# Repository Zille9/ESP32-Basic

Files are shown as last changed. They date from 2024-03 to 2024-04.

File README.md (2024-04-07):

# ESP32-Basic with FabGL VGA library + PS2-Keyboard
### Basic32+ with FabGL VGA library + PS2 PS2Controller for VGA monitor output - 2019 - 2023       
#### Ursprungsversion von: Rob Cai <rocaj74@gmail.com>
#### erweitert/modifiziert von:Reinhard Zielinski <zille09@gmail.com>                                                                   
#### Das Ergebnis ist ein kleiner Retro-Computer mit folgender Ausstattung:
- (Schaltplan siehe Ordner Schematic) 

## Hardware:
```
-ESP32 / 240MHz
-56472 Basic Bytes free
-VGA-Display 320x240 Pixel 64 Farben , AV (IO26) oder TFT-Screen 320x240 Pixel
-IO-Erweiterung mit MCP23017 (2x8 IO-Ports) + EEPROM 512kB 
-CardKb als PS2-Tastatur nutzbar (siehe Ordner <src/CardKeyBoard_neu>)
-Unterstützung von externem SPI-RAM 128kB, 512kB (Adafruit SPI-Fram) oder 2, 4 oder 8 MB PSRAM im SPI-Mode
-PS2-Keyboard 
-RTC DS3231 
-SD-Card
```

## Software:
```
Die Ursprungsversion wurde durch folgende Funktionen erweitert  

-fliesskomma Arithmetik
-Grafikfunktionen 	
-mathematische Funktionen 	
-Stringfunktionen 	
-lange Variablennamen  	
-viele zusätzliche Befehle (DATA,READ,STRG$,LEFT$,RIGHT$,MID$,POS,TAB,SPC,SIN,COS,TAN,ATN,LOG,SQR,PI usw.) 	
-erweiterte logische Operatoren (AND, OR) 	
-BIT-Manipulation &,|,%,<<,>> usw. 	
-Klammerrechnung 	
-IF THEN ELSE Abfragen 	
-Speichermonitor 	
-Exponential-Ein/Ausgabe 	
-Verschiedene Sensoren und Komponenten HC-S04, Dallas DS18S20, DHT, LCD, Neopixel-LED, BMP180 	
-Zeileneditor 
-BMP-Bilddatei-Import / Export
-Spritefunktionen (noch in der Entwicklung)
-Soundfunktionen (noch in der Entwicklung)
-integrierte Kurzhilfe
-Binärprogramme können mit RUN"/xxx.bin" gestartet werden - siehe Ordner <Software>

```

***Special Thanks on Guido Lehwalder and Marcelo Dantas ->RUN-CPM is a great Work!***

***Also thanks on Fabrizio Di Vittorio for the excellent FabGl-Library***



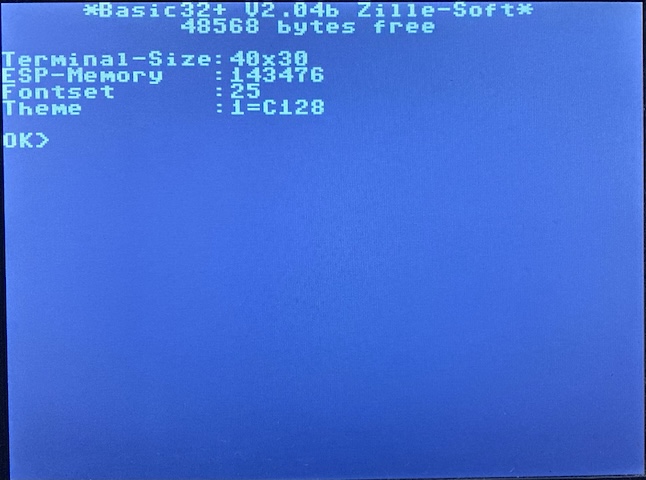
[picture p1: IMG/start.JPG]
Startbildschirm
 
```
-Startbildschirm
```

Commands
```
-Basic-Befehle
```

Functions 
```
-Basic -Funktionen
```

Programm Globus.Bas
```
-Programm Globus.Bas
```

Darstellung einer BMP-Datei
```
-Darstellung einer BMP-Datei
```

Programmlisting
```
-Programmlisting
```

Screenshot als BMP-Datei exportiert
```
Screenshot als BMP-Datei exportiert
```

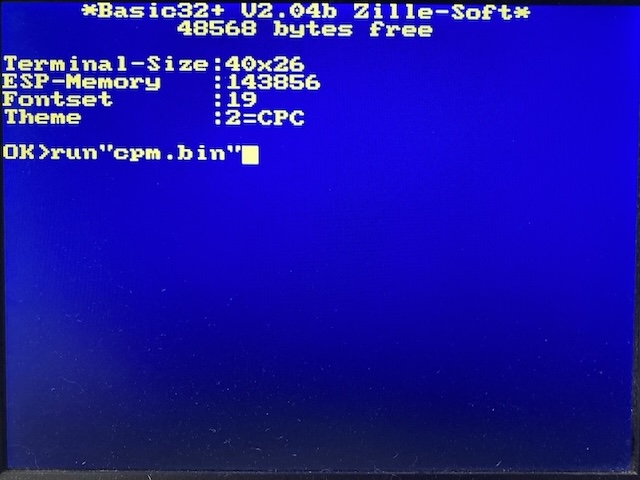
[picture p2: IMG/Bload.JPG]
..mit RUN kann dann auch CPM gestartet werden

```
...mit RUN kann dann auch CPM gestartet werden.
```

..RUN-CPM-Startbildschirm
```
...RUN-CPM Startbildschirm , mit EXIT kehrt man wieder zum Basic32+ zurück.
```

..Darstellung der Grid-Funktion
```
...der GRID-Befehl in Aktion .
```

## Bibliotheken einbinden und Basic32+ compilieren:
```
-die im Ordner libraries liegenden Unterverzeichnisse ins Arduino libraries-Verzeichnis kopieren

-zusätzlich die FabGL-lib mit dem Bibliotheksmanager der Arduino-IDE installieren

-die Quellen befinden sich im Ordner "src/FabGL-Basic" ->kompilieren und in den ESP32 laden

-den Inhalt des Verzeichnisses SD-Card auf eine SD-Karte kopieren .... und mit ESP32+Basic loslegen :-)

Im Ordner RUN-CPM befindet sich die um den OTA-Loader erweiterte Variante, um nach Eingabe von EXIT wieder zum Basic zurückzukehren.
```

## Komponenten:

-ESP32 NodeMCU https://www.berrybase.de/esp32-nodemcu-development-board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

-MCP23017 https://www.reichelt.de/i-o-erweiterung-16bit-1-8-5v-seriell-i2c-dip-28-mcp-23017-e-sp-p140074.html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

-FRAM 512kB https://www.adafruit.com/product/4719

-SD-Card Modul https://www.reichelt.de/arduino-sd-karten-modul-ard-module-sd-p282683.html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

-RTC-Modul https://www.reichelt.de/entwicklerboards-praezisions-echtzeituhr-ds3231-debo-rtc-uhr2-p235506.html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

-siehe auch BOOM-List im Ordner Schematic ->folgt bald

 ### Author:Reinhard Zielinski <zille09@gmail.com> April 2021

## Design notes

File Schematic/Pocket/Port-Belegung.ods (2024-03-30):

 | ESP-Buchse |  |  |  | MCP23017
1 | IO36 | 2 | GND | 1 | GND | 2 | GND
3 | IO39 | 4 | 3,3V | 3 | 3,3V | 4 | 3,3V
5 | IO34 | 6 | RESET | 5 | B0 | 6 | A7
7 | IO35 | 8 | SCL | 7 | B1 | 8 | A6
9 | IO12 | 10 | SDA | 9 | B2 | 10 | A5
11 | NC | 12 | MOSI / IO17 | 11 | B3 | 12 | A4
13 | IO27 | 14 | MISO / IO16 | 13 | B4 | 14 | A3
15 | IO26 | 16 | SCLK / IO14 | 15 | B5 | 16 | A2
17 | IO25 | 18 | 3,3V | 17 | B6 | 18 | A1
19 | IO2 | 20 | GND | 19 | B7 | 20 | A0
 |  | IN/OUT
 |  | IN

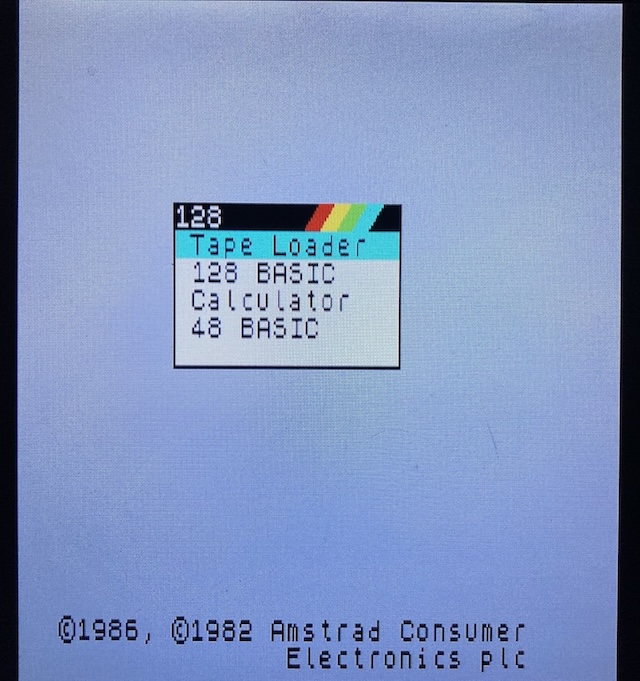
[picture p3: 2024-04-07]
IMG/spectrum.JPG

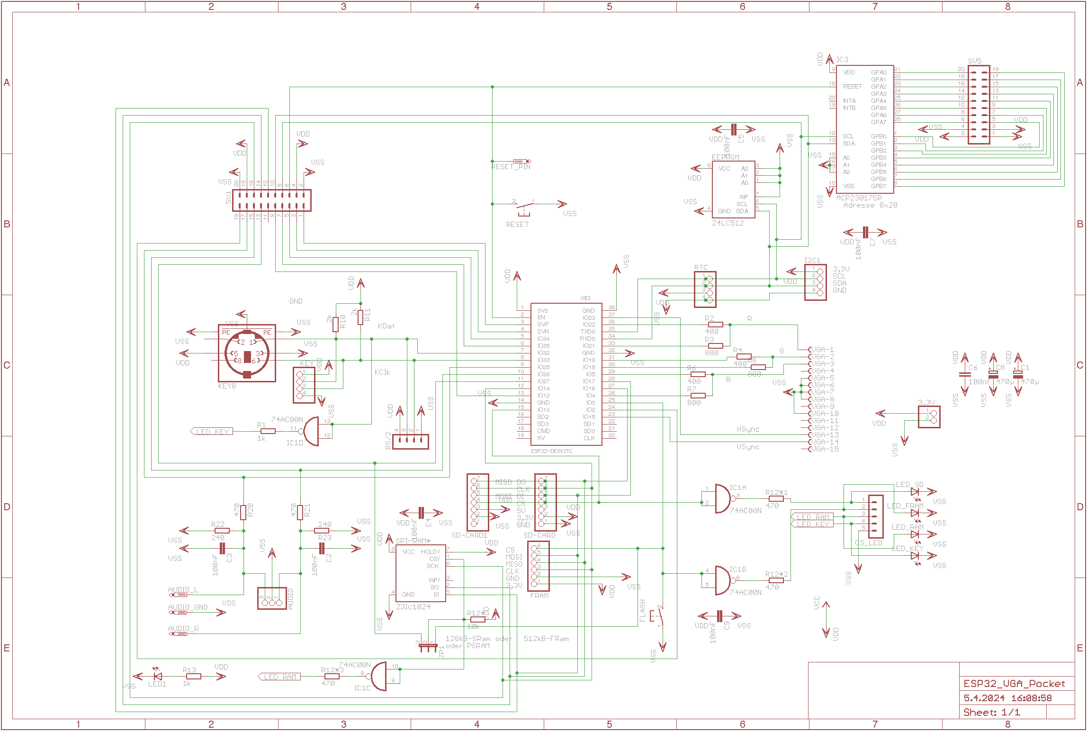
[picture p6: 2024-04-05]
Schematic/Pocket/Pocket_Schematic.png

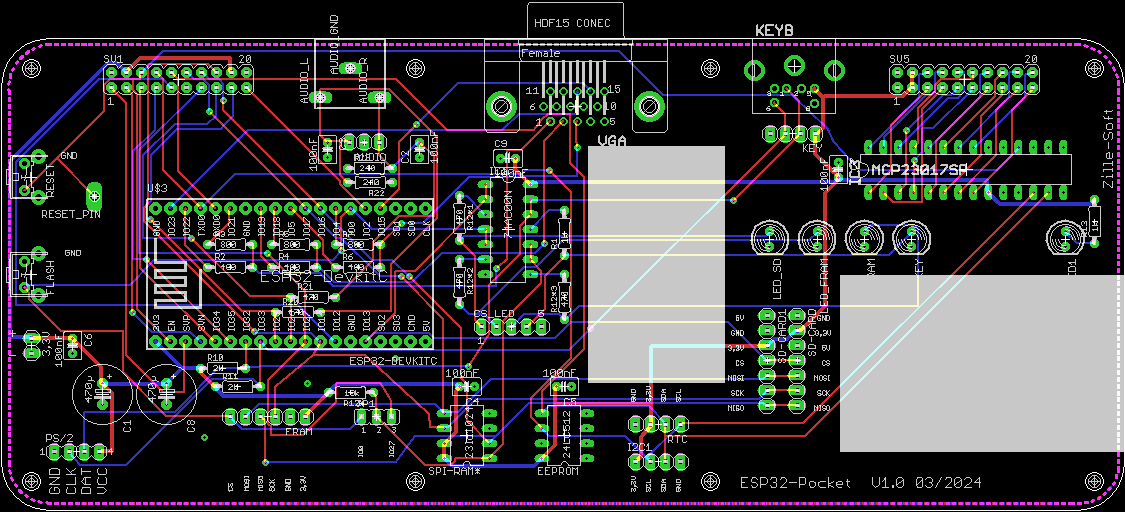
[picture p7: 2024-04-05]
Schematic/Pocket/Pocket_PCB.png

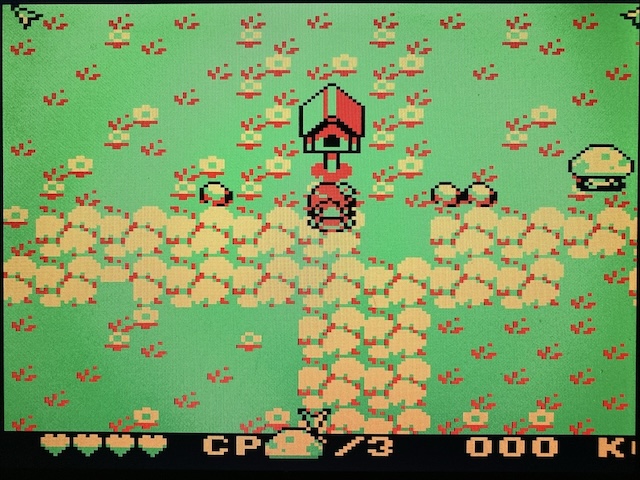
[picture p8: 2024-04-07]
IMG/gameboy.JPG

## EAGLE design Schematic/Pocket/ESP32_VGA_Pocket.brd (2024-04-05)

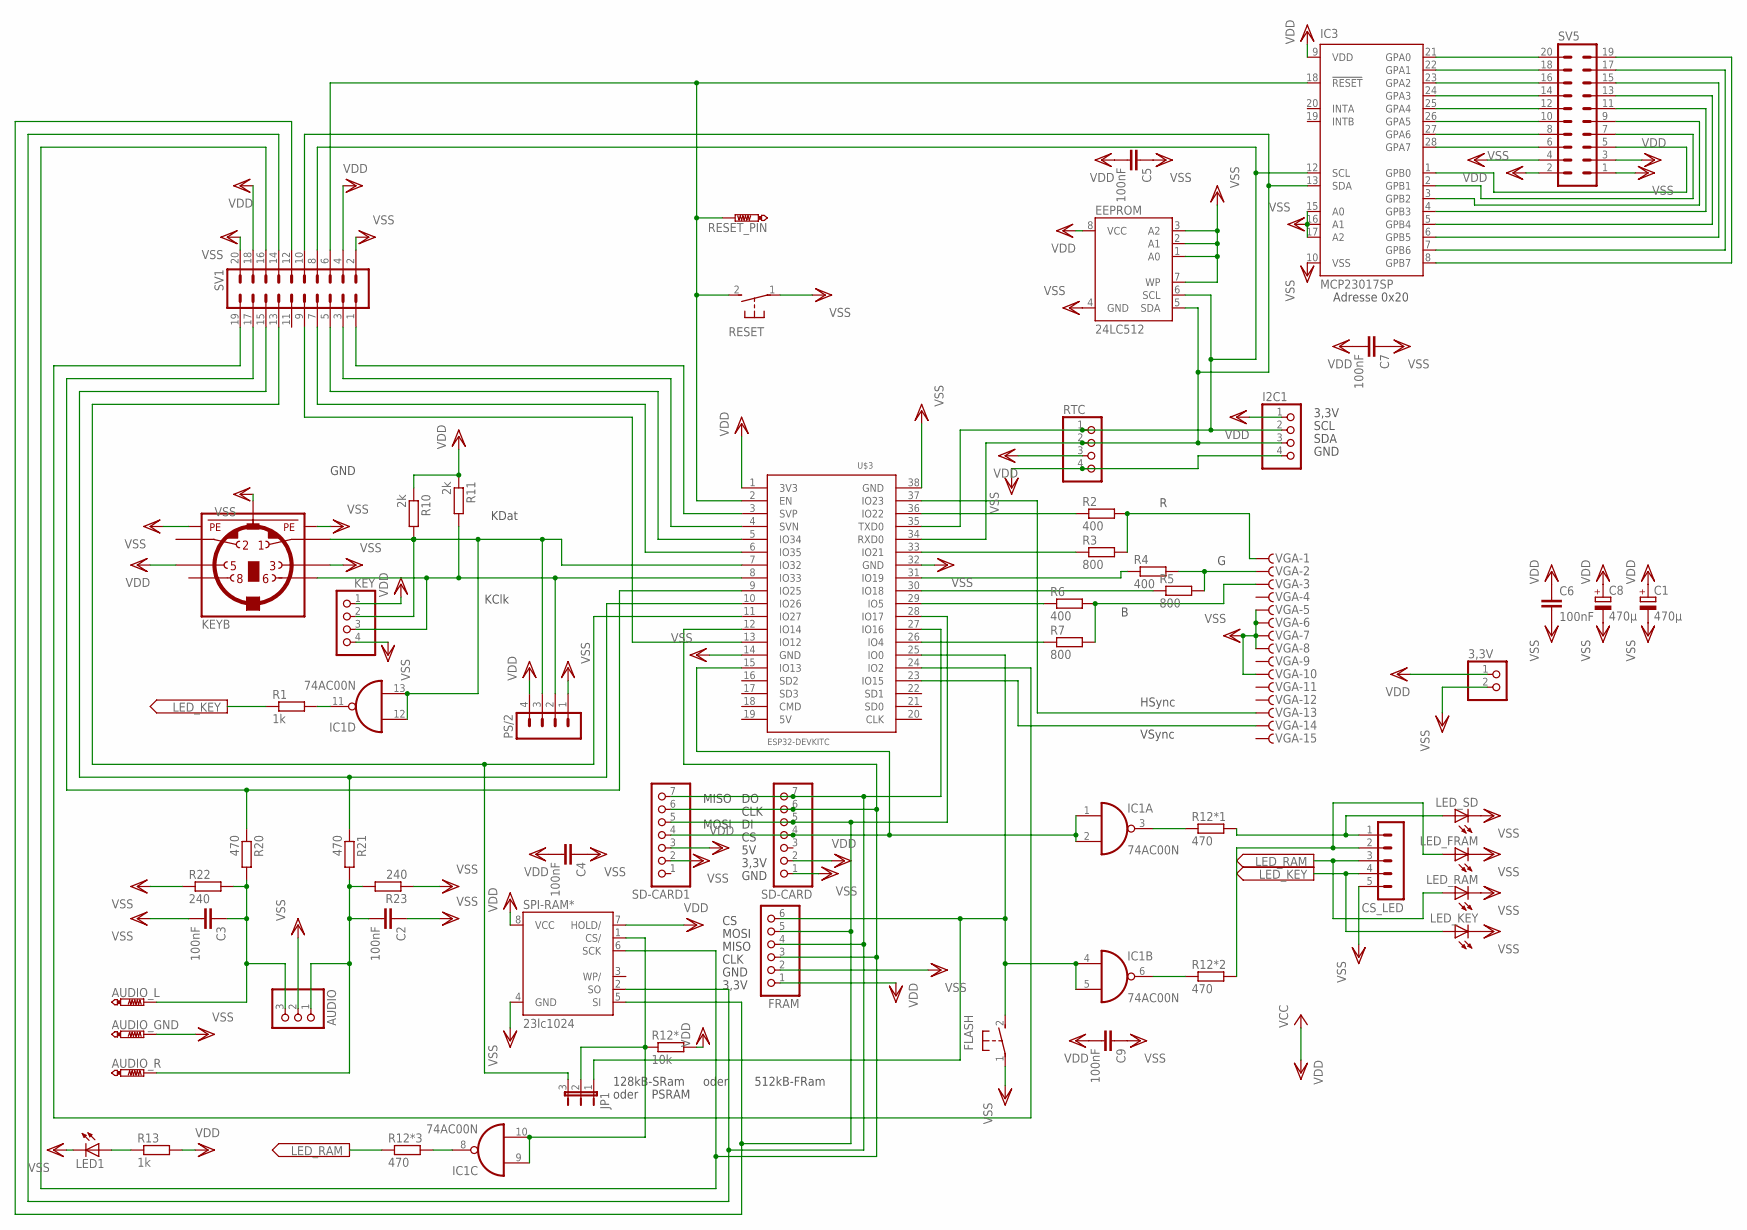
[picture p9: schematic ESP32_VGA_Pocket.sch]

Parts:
3,3V: PINHD-1X2; 1X02
AUDIO: PINHD-1X3; 1X03
AUDIO_GND: PTR1PAD1-13Y; P1-13Y
AUDIO_L: PTR1PAD1-13Y; P1-13Y
AUDIO_R: PTR1PAD1-13Y; P1-13Y
C1, C8: 470µ; E3,5-10
C2, C3, C4, C5, C6, C7, C9: 100nF; C025-030X050
CS_LED: MA05-1
EEPROM: 24LC512; DIL08
FLASH: 31-XX; B3F-31XX; MPN B3F-3100
FRAM: PINHD-1X6; 1X06
I2C1: PINHD-1X4; 1X04
IC1: 74AC00N; DIL14
IC3: MCP23017SP; DIL28-3; MPN MCP23017-E/SO
JP1: JP2E; JP2
KEY: PINHD-1X4; 1X04
KEYB: MINI_DIN_6; M_DIN6
LED1: LED5MM
LED_FRAM: LED5MM
LED_KEY: LED5MM
LED_RAM: LED5MM
LED_SD: LED5MM
PS/2: MA04-1
R1, R13: 1k; 0204/7
R2, R4, R6: 400; 0204/7
R3, R5, R7: 800; 0204/7
R10, R11: 2k; 0204/7
R12*: 10k; 0204/7
R12*1, R12*2, R12*3, R20, R21: 470; 0204/7
R22, R23: 240; 0204/7
RESET: 31-XX; B3F-31XX
RESET_PIN: PTR1PAD1-17Y; P1-17Y
RTC: PINHD-1X4; 1X04
SD-CARD, SD-CARD1: PINHD-1X7; 1X07
SPI-RAM*: 23lc1024; DIL08
SV1, SV5: MA10-2
U$3: ESP32DEVKITC; ESP32-DEVKITC
VGA: F15HDHS; HDF15H

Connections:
AUDIO1: AUDIO.3, AUDIO_L.TP, C3.1, R20.2, R22.2
AUDIO2: AUDIO.1, AUDIO_R.TP, C2.2, R21.2, R23.2
CLK: FRAM.3, SD-CARD.6, SD-CARD1.6, SPI-RAM*.6 (SCK), SV1.16, U$3.12 (IO14)
CLK_K: KEY.3, KEYB.6, PS/2.2, R11.2, U$3.8 (IO33)
CS_RAM: IC1.9 (I0), IC1.10 (I1), JP1.2, R12*.1, SPI-RAM*.1 (CS/)
CS_SD: IC1.1 (I0), IC1.2 (I1), SD-CARD.4, SD-CARD1.4, U$3.15 (IO13)
DAT_K: IC1.12 (I0), IC1.13 (I1), KEY.2, KEYB.1, PS/2.3, R10.2, U$3.7 (IO32)
FLASH: FLASH.2 (S), FRAM.6, IC1.4 (I0), IC1.5 (I1), JP1.1, U$3.25 (IO0)
GND: IC1.7 (GND)
IO2: SV1.19, U$3.24 (IO2)
IO12: SV1.9, U$3.13 (IO12)
IO27: JP1.3, SV1.13, U$3.11 (IO27)
IO34: SV1.5, U$3.5 (IO34)
IO35: SV1.7, U$3.6 (IO35)
IO36: SV1.1, U$3.3 (SVP)
IO39: SV1.3, U$3.4 (SVN)
LED_FRAM: CS_LED.2, LED_FRAM.A, R12*2.2
LED_KEY: CS_LED.4, LED_KEY.A, R1.1
LED_RAM: CS_LED.3, LED_RAM.A, R12*3.1
LED_SD: CS_LED.1, LED_SD.A, R12*1.2
MISO: FRAM.4, SD-CARD.7, SD-CARD1.7, SPI-RAM*.2 (SO), SV1.14, U$3.27 (IO16)
MOSI: FRAM.5, SD-CARD.5, SD-CARD1.5, SPI-RAM*.5 (SI), SV1.12, U$3.28 (IO17)
unnamed: R20.1, SV1.17, U$3.9 (IO25)
unnamed: IC1.3 (O), R12*1.1
unnamed: R21.1, SV1.15, U$3.10 (IO26)
unnamed: IC1.11 (O), R1.2
unnamed: IC1.6 (O), R12*2.1
unnamed: IC1.8 (O), R12*3.2
unnamed: LED1.A, R13.1
unnamed: IC3.1 (GPB0), SV5.5
unnamed: IC3.21 (GPA0), SV5.20
unnamed: IC3.22 (GPA1), SV5.18
unnamed: IC3.23 (GPA2), SV5.16
unnamed: IC3.24 (GPA3), SV5.14
unnamed: IC3.25 (GPA4), SV5.12
unnamed: IC3.26 (GPA5), SV5.10
unnamed: IC3.27 (GPA6), SV5.8
unnamed: IC3.28 (GPA7), SV5.6
unnamed: IC3.2 (GPB1), SV5.7
unnamed: IC3.3 (GPB2), SV5.9
unnamed: IC3.4 (GPB3), SV5.11
unnamed: IC3.5 (GPB4), SV5.13
unnamed: IC3.6 (GPB5), SV5.15
unnamed: IC3.7 (GPB6), SV5.17
unnamed: IC3.8 (GPB7), SV5.19
unnamed: R6.2, R7.2, VGA.3
unnamed: R4.2, R5.2, VGA.2
unnamed: R2.2, R3.2, VGA.1
unnamed: R2.1, U$3.36 (IO22)
unnamed: R3.1, U$3.33 (IO21)
unnamed: R4.1, U$3.31 (IO19)
unnamed: R5.1, U$3.30 (IO18)
unnamed: R6.1, U$3.29 (IO5)
unnamed: R7.1, U$3.26 (IO4)
unnamed: U$3.37 (IO23), VGA.13
unnamed: U$3.23 (IO15), VGA.14
RESET: IC3.18 (!RESET), RESET.2 (S), RESET_PIN.TP, SV1.6, U$3.2 (EN)
SCL: EEPROM.6 (SCL), I2C1.2, IC3.12 (SCL), RTC.1, SV1.8, U$3.35 (TXD0)
SDA: EEPROM.5 (SDA), I2C1.3, IC3.13 (SDA), RTC.2, SV1.10, U$3.34 (RXD0)
VDD: 3,3V.1, C1.+, C4.2, C5.2, C6.1, C7.2, C8.+, C9.2, EEPROM.8 (VCC), FRAM.1, I2C1.1, IC1.14 (VCC), IC3.9 (VDD), KEY.1, KEYB.5, PS/2.4, R10.1, R11.1, R12*.2, R13.2, RTC.3, SD-CARD.2, SD-CARD1.3, SPI-RAM*.7 (HOLD/), SPI-RAM*.8 (VCC), SV1.4, SV1.18, SV5.3, SV5.4, U$3.1 (3V3)
VSS: 3,3V.2, AUDIO.2, AUDIO_GND.TP, C1.-, C2.1, C3.2, C4.1, C5.1, C6.2, C7.1, C8.-, C9.1, CS_LED.5, EEPROM.1 (A0), EEPROM.2 (A1), EEPROM.3 (A2), EEPROM.4 (GND), EEPROM.7 (WP), FLASH.1, FRAM.2, I2C1.4, IC3.10 (VSS), IC3.15 (A0), IC3.16 (A1), IC3.17 (A2), KEY.4, KEYB.3, KEYB.SH1 (PE1), KEYB.SH2 (PE2), KEYB.SH3 (PE3), LED1.K (C), LED_FRAM.K (C), LED_KEY.K (C), LED_RAM.K (C), LED_SD.K (C), PS/2.1, R22.1, R23.1, RESET.1, RTC.4, SD-CARD.1, SD-CARD1.2, SPI-RAM*.4 (GND), SV1.2, SV1.20, SV5.1, SV5.2, U$3.14 (GND), U$3.32 (GND), U$3.38 (GND), VGA.5, VGA.6, VGA.7, VGA.8, VGA.10

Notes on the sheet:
CLK
MISO
MOSI
KDat
KClk
VSync
HSync
GND
SCL
SDA
3,3V
128kB-SRam
512kB-FRam
oder
Adresse 0x20
PSRAM

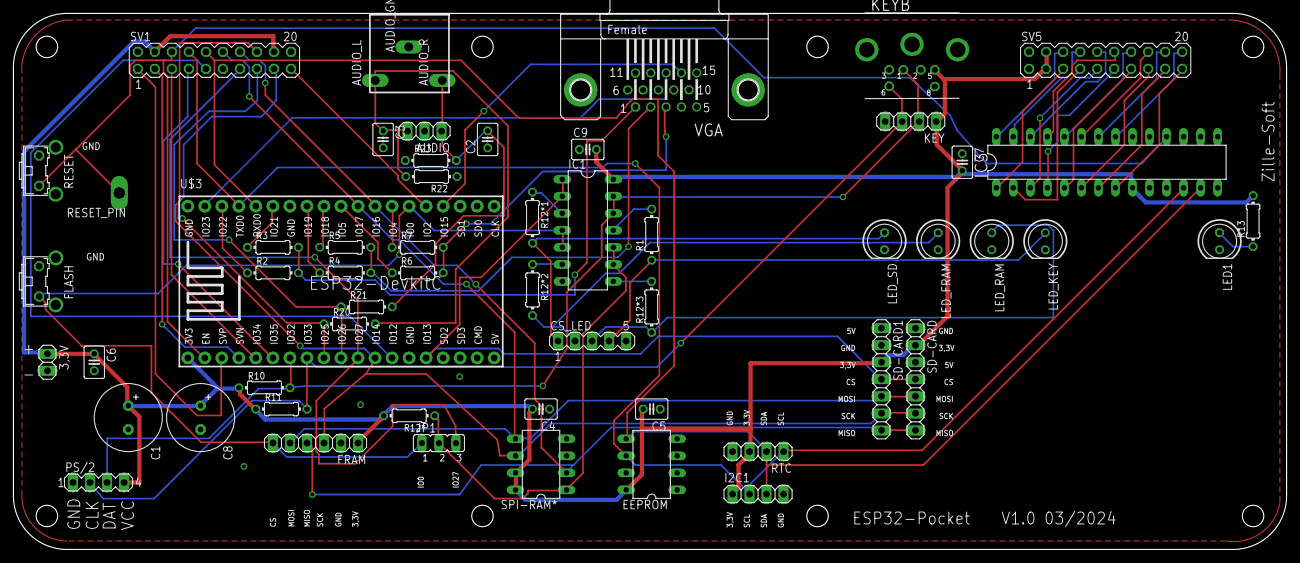
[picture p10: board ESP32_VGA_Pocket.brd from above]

Board: 2 copper layers, 190.0 x 80.0 mm, 58 parts (0 on the bottom side), 60 nets.

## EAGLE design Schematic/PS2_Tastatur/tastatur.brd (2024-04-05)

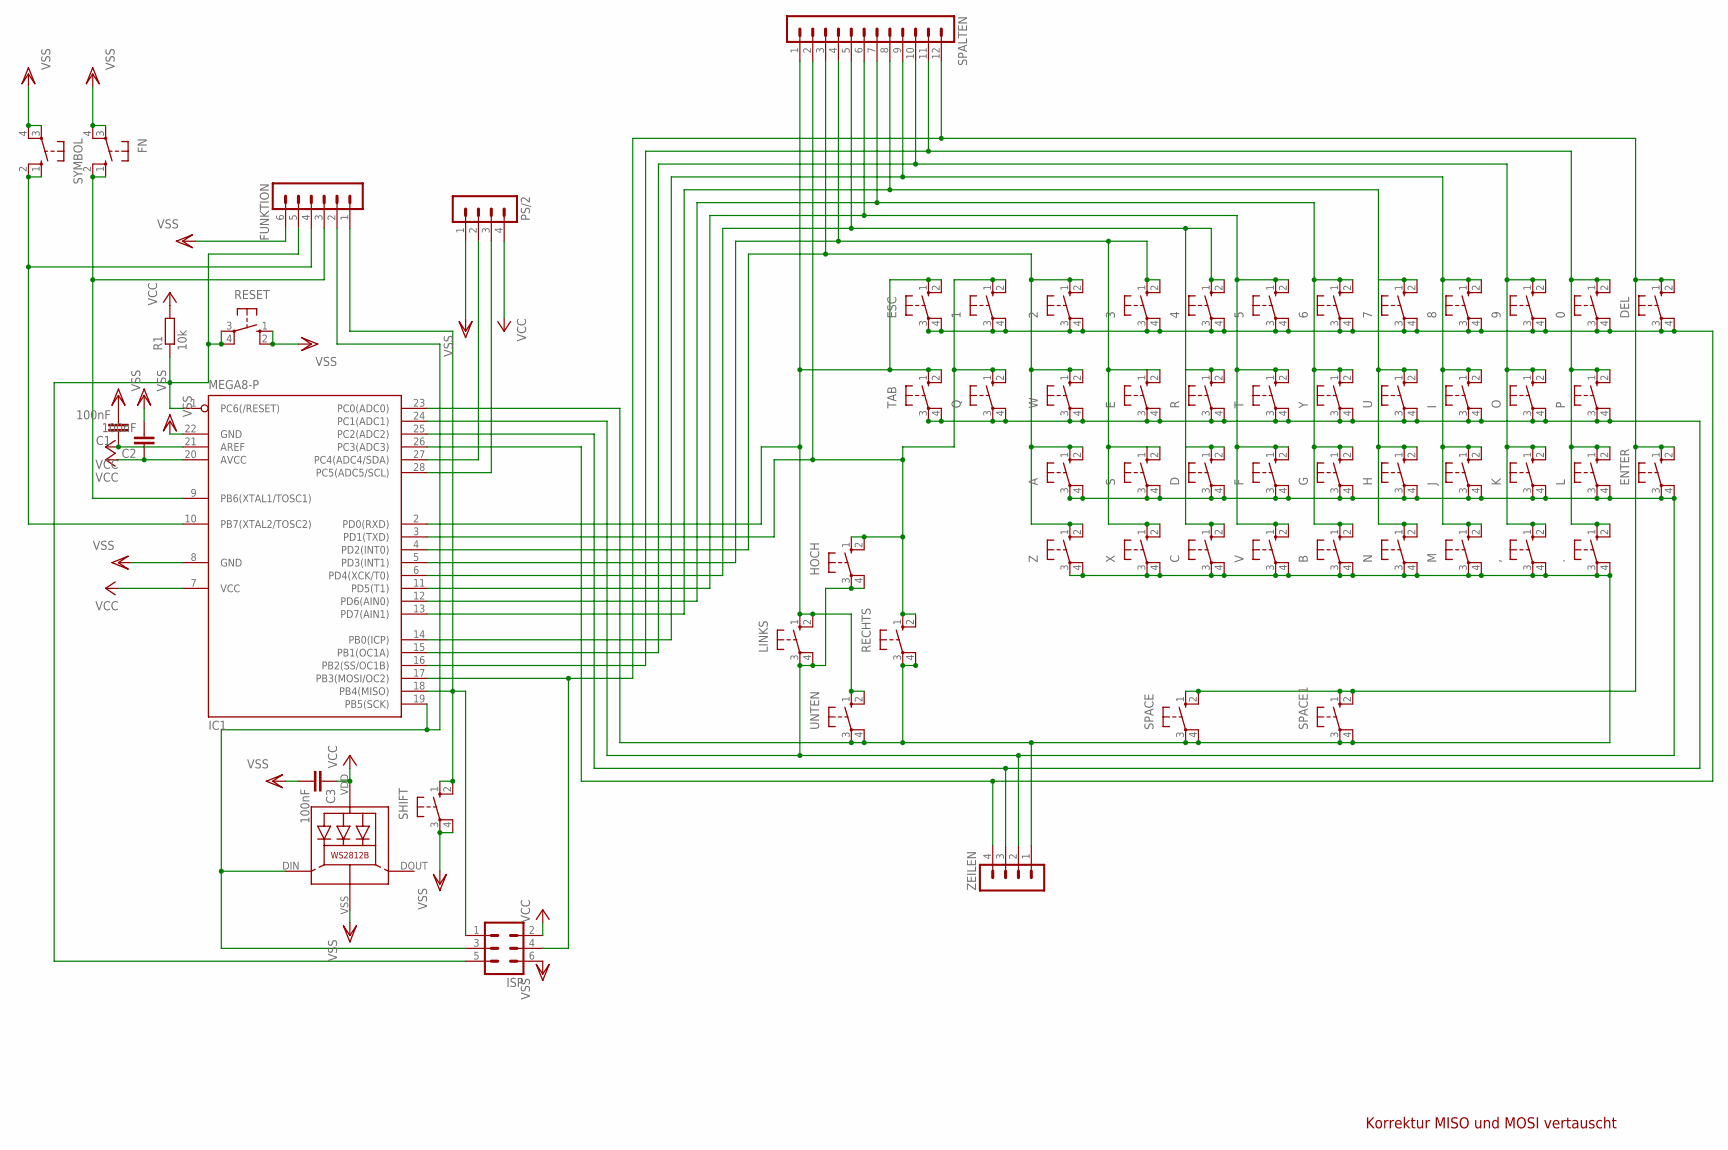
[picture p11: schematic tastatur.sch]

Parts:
0, 1, 2, 3, 4, 5, 6, 7, 8, 9, .: 40-XX; B3F-40XX
,: 40-XX; B3F-40XX
A: 40-XX; B3F-40XX
B: 40-XX; B3F-40XX
C: 40-XX; B3F-40XX
C1, C2, C3: 100nF; C025-025X050
D: 40-XX; B3F-40XX
DEL: 40-XX; B3F-40XX
E: 40-XX; B3F-40XX
ENTER: 40-XX; B3F-40XX
ESC: 40-XX; B3F-40XX
F: 40-XX; B3F-40XX
FN: 40-XX; B3F-40XX
FUNKTION: MA06-1
G: 40-XX; B3F-40XX
H: 40-XX; B3F-40XX
HOCH: 40-XX; B3F-40XX; MPN B3F-4000
I: 40-XX; B3F-40XX
IC1: MEGA8-P; DIL28-3
ISP: ML6L
J: 40-XX; B3F-40XX
K: 40-XX; B3F-40XX
L: 40-XX; B3F-40XX
LED1: WS2812B
LINKS: 40-XX; B3F-40XX; MPN B3F-4000
M: 40-XX; B3F-40XX
N: 40-XX; B3F-40XX
O: 40-XX; B3F-40XX
P: 40-XX; B3F-40XX
PS/2: MA04-1
Q: 40-XX; B3F-40XX
R: 40-XX; B3F-40XX
R1: 10k; 0204/7
RECHTS: 40-XX; B3F-40XX; MPN B3F-4000
RESET: 10-XX; B3F-10XX
S: 40-XX; B3F-40XX
SHIFT: 40-XX; B3F-40XX
SPACE: 40-XX; B3F-40XX; MPN B3F-4000
SPACE1: 40-XX; B3F-40XX
SPALTEN: MA12-1
SYMBOL: 40-XX; B3F-40XX
T: 40-XX; B3F-40XX
TAB: 40-XX; B3F-40XX
U: 40-XX; B3F-40XX
UNTEN: 40-XX; B3F-40XX; MPN B3F-4000
V: 40-XX; B3F-40XX
W: 40-XX; B3F-40XX
X: 40-XX; B3F-40XX
Y: 40-XX; B3F-40XX
Z: 40-XX; B3F-40XX
ZEILEN: MA04-1

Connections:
A0: ,.3, ,.4 (P1), ..3, ..4 (P1), B.3, B.4 (P1), C.3, C.4 (P1), IC1.23 (PC0(ADC0)), M.3, M.4 (P1), N.3, N.4 (P1), RECHTS.3, RECHTS.4 (P1), SPACE.3, SPACE.4 (P1), SPACE1.3, SPACE1.4 (P1), UNTEN.3, UNTEN.4 (P1), V.3, V.4 (P1), X.3, X.4 (P1), Z.3, Z.4 (P1), ZEILEN.1
A1: A.3, A.4 (P1), D.3, D.4 (P1), ENTER.3, ENTER.4 (P1), F.3, F.4 (P1), G.3, G.4 (P1), H.3, H.4 (P1), HOCH.3, HOCH.4 (P1), IC1.24 (PC1(ADC1)), J.3, J.4 (P1), K.3, K.4 (P1), L.3, L.4 (P1), LINKS.3, LINKS.4 (P1), S.3, S.4 (P1), ZEILEN.2
A2: E.3, E.4 (P1), I.3, I.4 (P1), IC1.25 (PC2(ADC2)), O.3, O.4 (P1), P.3, P.4 (P1), Q.3, Q.4 (P1), R.3, R.4 (P1), T.3, T.4 (P1), TAB.3, TAB.4 (P1), U.3, U.4 (P1), W.3, W.4 (P1), Y.3, Y.4 (P1), ZEILEN.3
A3: 0.3, 0.4 (P1), 1.3, 1.4 (P1), 2.3, 2.4 (P1), 3.3, 3.4 (P1), 4.3, 4.4 (P1), 5.3, 5.4 (P1), 6.3, 6.4 (P1), 7.3, 7.4 (P1), 8.3, 8.4 (P1), 9.3, 9.4 (P1), DEL.3, DEL.4 (P1), ESC.3, ESC.4 (P1), IC1.26 (PC3(ADC3)), ZEILEN.4
CLK: IC1.27 (PC4(ADC4/SDA)), PS/2.2
D0: ESC.1 (S), ESC.2 (S1), IC1.2 (PD0(RXD)), LINKS.1 (S), LINKS.2 (S1), SPALTEN.1, TAB.1 (S), TAB.2 (S1), UNTEN.1 (S), UNTEN.2 (S1)
D1: 1.1 (S), 1.2 (S1), HOCH.1 (S), HOCH.2 (S1), IC1.3 (PD1(TXD)), Q.1 (S), Q.2 (S1), RECHTS.1 (S), RECHTS.2 (S1), SPALTEN.2
D2: 2.1 (S), 2.2 (S1), A.1 (S), A.2 (S1), IC1.4 (PD2(INT0)), SPALTEN.3, W.1 (S), W.2 (S1), Z.1 (S), Z.2 (S1)
D3: 3.1 (S), 3.2 (S1), E.1 (S), E.2 (S1), IC1.5 (PD3(INT1)), S.1 (S), S.2 (S1), SPALTEN.4, X.1 (S), X.2 (S1)
D4: 4.1 (S), 4.2 (S1), C.1 (S), C.2 (S1), D.1 (S), D.2 (S1), IC1.6 (PD4(XCK/T0)), R.1 (S), R.2 (S1), SPALTEN.5
D5: 5.1 (S), 5.2 (S1), F.1 (S), F.2 (S1), IC1.11 (PD5(T1)), SPALTEN.6, T.1 (S), T.2 (S1), V.1 (S), V.2 (S1)
D6: 6.1 (S), 6.2 (S1), B.1 (S), B.2 (S1), G.1 (S), G.2 (S1), IC1.12 (PD6(AIN0)), SPALTEN.7, Y.1 (S), Y.2 (S1)
D7: 7.1 (S), 7.2 (S1), H.1 (S), H.2 (S1), IC1.13 (PD7(AIN1)), N.1 (S), N.2 (S1), SPALTEN.8, U.1 (S), U.2 (S1)
D8: 8.1 (S), 8.2 (S1), I.1 (S), I.2 (S1), IC1.14 (PB0(ICP)), J.1 (S), J.2 (S1), M.1 (S), M.2 (S1), SPALTEN.9
D9: 9.1 (S), 9.2 (S1), ,.1 (S), ,.2 (S1), IC1.15 (PB1(OC1A)), K.1 (S), K.2 (S1), O.1 (S), O.2 (S1), SPALTEN.10
D10: 0.1 (S), 0.2 (S1), ..1 (S), ..2 (S1), IC1.16 (PB2(SS/OC1B)), L.1 (S), L.2 (S1), P.1 (S), P.2 (S1), SPALTEN.11
D11: DEL.1 (S), DEL.2 (S1), ENTER.1 (S), ENTER.2 (S1), IC1.17 (PB3(MOSI/OC2)), ISP.4, SPACE.1 (S), SPACE.2 (S1), SPACE1.1 (S), SPACE1.2 (S1), SPALTEN.12
DAT: IC1.28 (PC5(ADC5/SCL)), PS/2.3
DIN: FUNKTION.2, IC1.19 (PB5(SCK)), ISP.3, LED1.DIN (DI)
FN: FN.1 (S), FN.2 (S1), FUNKTION.3, IC1.9 (PB6(XTAL1/TOSC1))
RESET: FUNKTION.5, IC1.1 (PC6(/RESET)), ISP.5, R1.1, RESET.3, RESET.4 (P1)
SHIFT: FUNKTION.1, IC1.18 (PB4(MISO)), ISP.1, SHIFT.1 (S), SHIFT.2 (S1)
SYMBOL: FUNKTION.4, IC1.10 (PB7(XTAL2/TOSC2)), SYMBOL.1 (S), SYMBOL.2 (S1)
VCC: C1.1, C2.1, C3.1, IC1.7 (VCC), IC1.20 (AVCC), IC1.21 (AREF), ISP.2, LED1.VDD, PS/2.4, R1.2
VSS: C1.2, C2.2, C3.2, FN.3, FN.4 (P1), FUNKTION.6, IC1.8 (GND), IC1.22 (GND), ISP.6, LED1.VSS (GND), PS/2.1, RESET.1 (S), RESET.2 (S1), SHIFT.3, SHIFT.4 (P1), SYMBOL.3, SYMBOL.4 (P1)

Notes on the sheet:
Korrektur MISO und MOSI vertauscht

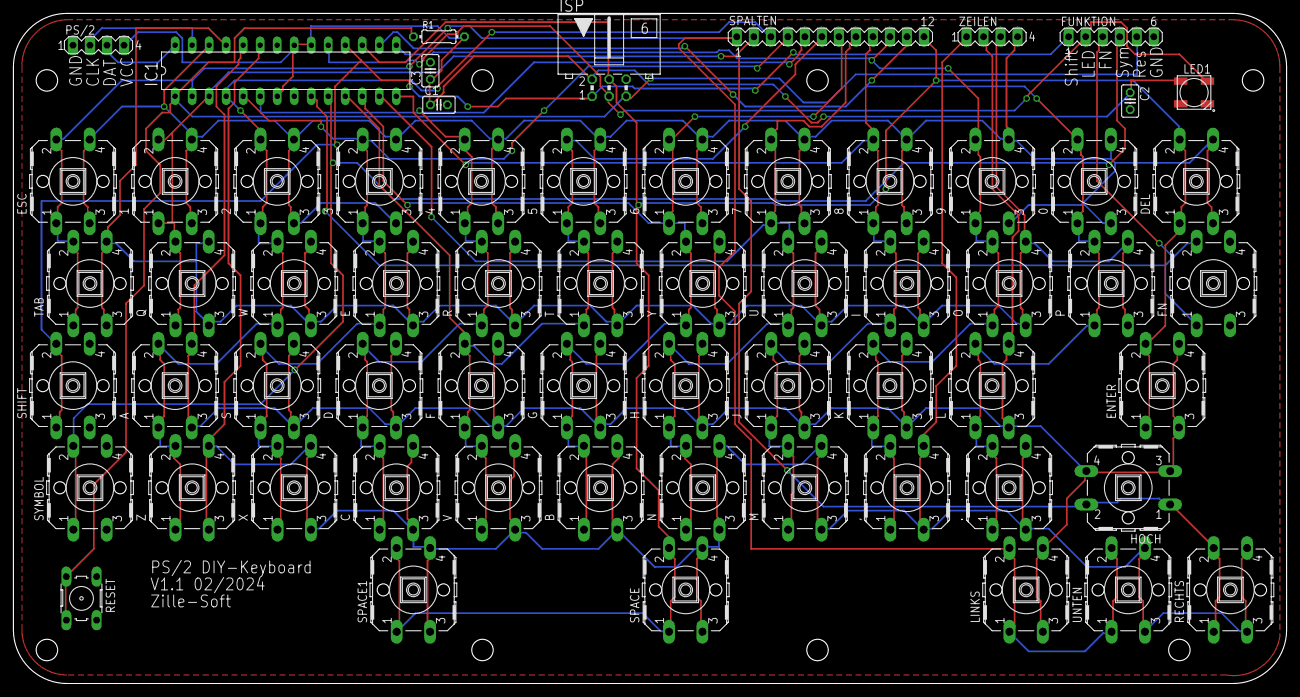
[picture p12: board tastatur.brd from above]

Board: 2 copper layers, 190.0 x 100.0 mm, 63 parts (0 on the bottom side), 25 nets.

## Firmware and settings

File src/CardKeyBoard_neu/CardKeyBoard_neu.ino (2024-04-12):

//
// CardKeyBoard.ino
// PS/2 Version - Author:Herr Tamakichi
// 2019/03/08
// Erforderliche Bibliothek
// ps2dev https://playground.arduino.cc/uploads/ComponentLib/ps2dev.zip
// Adafruit_NeoPixel
//
// 2023/12/30 stark angepasste Version
// für die korrekte Darstellung muss am Host-Computer die japanische Tastatur angegeben werden
//
// **********************************************************************************************************************************
// * HINWEIS ZUM BRENNEN: MiniCore 328P - no Bootloader - 8MHz intern - STK500 as ISP (MiniCore) einstellen                         *
// * seltsamerweise funktioniert der Controller erst nach dem Versuch den Bootloader zu brennen - wird mit Fehlermeldung quittiert  *
// * danach das Programm flashen - dann sollte alles funktionieren                                                                  *
// *                                                                                                                                *
// * Hinweis zum Keyboard-PCB V1.0 - MISO und MOSI sind vertauscht, das muss berücksichtigt werden, damit der Brenner funktioniert  *
// **********************************************************************************************************************************
// * noch startet der Tastatur treiber nicht immer korrekt -> behoben (siehe loop kayboard.available() - variable startup - wird gesetzt
// * funktioniert aber nur beim Einschalten - Resetverbindung zur Hostanwendung würde beim Reset die Variable zurücksetzen
// * Auto-Repeat hinzugefügt - noch nicht perfekt - irgendwie stimmt das Timing noch nicht
// * Funktion soweit zufriedenstellend - Start der Tastatur jetzt auch zuverlässig
// * Ctrl-Taste implementiert - Fn einfach dient als Ctrl-Taste (nur Buchstaben a-z)
//
#include <Adafruit_NeoPixel.h>
#include <ps2dev.h>
#define KB_CLK      A4  // PS/2 CLK  
#define KB_DATA     A5  // PS/2 DATA 

#define PIN           13
#define NUMPIXELS      1

Adafruit_NeoPixel pixels = Adafruit_NeoPixel(NUMPIXELS, PIN, NEO_GRB + NEO_KHZ800);
PS2dev keyboard(KB_CLK, KB_DATA); // PS/2

#define Set_Bit(val, bitn)    (val |=(1<<(bitn)))
#define Clr_Bit(val, bitn)     (val&=~(1<<(bitn)))
#define Get_Bit(val, bitn)    (val &(1<<(bitn)) )

//       d0   d1     d2  d3 d4 d5 d6 d7 d8 d9 d10 d11
//A3：   esc   1      2  3  4  5  6  7  8  9  0   del
//A2:    tab   q      w  e  r  t  y  u  i  o  p
//A1:   left   up     a  s  d  f  g  h  j  k  l   enter
//A0:   down   right  z  x  c  v  b  n  m  ,  .   space
//sym: d15
//shift: d12
//fn: d14

int16_t old_no, first_no;
int dl, startup = 0;

#define shiftPressed (PINB & 0x10 ) != 0x10
#define symPressed (PINB & 0x80 ) != 0x80
#define fnPressed (PINB & 0x40 ) != 0x40

int _shift = 0, _fn = 0, _sym = 0, ctrl = 0, idle = 0;
unsigned char KEY = 0, hadPressed = 0, repeatkey = 0;
int Mode = 0; //0->normal.1->shift 2->long_shift, 3->sym, 4->long_sym 5->fn,6->long_fn



unsigned char KeyMap[48][7] =
{ //nor, shift,long_shift, sym,long_sym,fn,long_fn,
  {  27,  27,  27,  27,  27, 128, 128},//esc  0
  { '1', '1', '1', '!', '!', 129, 129},//1    1
  { '2', '2', '2', '"', '"', 130, 130},//2    2
  { '3', '3', '3', '\'', '\'', 131, 131},//3  3
  { '4', '4', '4', '$', '$', 132, 132},//4    4
  { '5', '5', '5', '%', '%', 133, 133},//5    5
  { '6', '6', '6', '&', '&', 134, 134},//6    6
  { '7', '7', '7', '/', '/', 135, 135},//7    7
  { '8', '8', '8', '(', '(', 136, 136},//8    8
  { '9', '9', '9', ')', ')', 137, 137},//9    9
  { '0', '0', '0', '=', '=', 138, 138},//0    10
  {  8 , 127 , 127,  8 ,  8 , 139, 139}, //del11
  {  9 ,  9 ,  9 ,  9 ,  9 , 140, 140},//tab  12
  { 'q', 'Q', 'Q', '{', '{', 141, 141},//q    13
  { 'w', 'W', 'W', '}', '}', 142, 142},//w    14
  { 'e', 'E', 'E', '+', '+', 143, 143},//e    15
  { 'r', 'R', 'R', '#', '#', 144, 144},//r    16
  { 't', 'T', 'T', '[', '[', 145, 145},//t    17
  { 'y', 'Y', 'Y', ']', ']', 146, 146}, //y   18
  { 'u', 'U', 'U', '|', '|', 147, 147},//u    19
  { 'i', 'I', 'I', '~', '~', 148, 148},//i    20
  { 'o', 'O', 'O', '^', '^', 149, 149}, //o   21
  { 'p', 'P', 'P', '*', '*', 150, 150},//p    22
  {  0 ,  0 ,  0 ,  0 ,  0 , 0, 0},    //  no key 23
  {  180,  180,  180,  180,  180, 152, 152},//LEFT 24
  {  181,  181,  181,  181,  181, 153, 153},//UP    25
  { 'a', 'A', 'A', '<', '<', 154, 154},//a    26
  { 's', 'S', 'S', '>', '>', 155, 155},//s    27
  { 'd', 'D', 'D', '@', '@', 156, 156},//d    28
  { 'f', 'F', 'F', 0, 0, 157, 157},//f        29
  { 'g', 'G', 'G', '-', '-', 158, 158},//g    30
  { 'h', 'H', 'H', '_', '_', 159, 159},//h    40
  { 'j', 'J', 'J', 0, 0, 160, 160},//j        41
  { 'k', 'K', 'K', '?', '?', 161, 161},//k    42
  { 'l', 'L', 'L',   0,   0, 162, 162},//l    43
  { 13 , 13 ,  13,  13,  13, 163, 163},//enter  44
  {  182, 182 ,  182,  182,  182, 164, 164},//DOWN  45
  {  183, 183 ,  183,  183,  183, 165, 165},//RIGHT 46
  { 'z', 'Z', 'Z',  0 ,  0 , 166, 166},//z    47
  { 'x', 'X', 'X',  0 ,  0 , 167, 167},//x    48
  { 'c', 'C', 'C',  0 ,  0 , 168, 168},//c    49
  { 'v', 'V', 'V',  0 ,  0 , 169, 169},//v    50
  { 'b', 'B', 'B',  0 ,  0 , 170, 170},//b    51
  { 'n', 'N', 'N',  0 ,  0 , 171, 171},//n    52
  { 'm', 'M', 'M',  0 ,  0 , 172, 172},//m    53
  { ',', ',', ',', ';', ';', 173, 173},//,    54
  { '.', '.', '.', ':', ':', 174, 174},//.    55
  { ' ' , ' ', ' ', ' ', ' ', 175, 175}//space 56
};

// ASCII-Code-zu-Scan-Code-Konvertierungstabelle
unsigned char ScanMap[121][3] = {
  // Zeichencode, 2 Bytes | Verschiebung, Scancode
  { 8, 0, 0x66 } , // Backspace
  { 9, 0, 0x0D } , // TAB
  { 13, 0, 0x5A } , // Enter
  { 27, 0, 0x76 } , // Esc
  { 32, 0, 0x29 } , // Space
  { 33, 1, 0x16 } , // !
  { 34, 1, 0x1E } , // "
  { 35, 1, 0x26 } , // #
  { 36, 1, 0x25 } , // $
  { 37, 1, 0x2E } , // %
  { 38, 1, 0x36 } , // &
  { 39, 1, 0x3D } , // '
  { 40, 1, 0x3E } , // (
  { 41, 1, 0x46 } , // )
  { 42, 1, 0x52 } , // *
  { 43, 1, 0x4C } , // +
  { 44, 0, 0x41 } , // ,
  { 45, 0, 0x4E } , // -
  { 46, 0, 0x49 } , // .
  { 47, 0, 0x4A } , // /
  { 48, 0, 0x45 } , // 0
  { 49, 0, 0x16 } , // 1
  { 50, 0, 0x1E } , // 2
  { 51, 0, 0x26 } , // 3
  { 52, 0, 0x25 } , // 4
  { 53, 0, 0x2E } , // 5
  { 54, 0, 0x36 } , // 6
  { 55, 0, 0x3D } , // 7
  { 56, 0, 0x3E } , // 8
  { 57, 0, 0x46 } , // 9
  { 58, 0, 0x52 } , // :
  { 59, 0, 0x4C } , // ;
  { 60, 1, 0x41 } , // <
  { 61, 1, 0x4E } , // =
  { 62, 1, 0x49 } , // >
  { 63, 1, 0x4A } , // ?
  { 64, 0, 0x54 } , // @
  { 65, 1, 0x1C } , // A   //37
  { 66, 1, 0x32 } , // B
  { 67, 1, 0x21 } , // C
  { 68, 1, 0x23 } , // D
  { 69, 1, 0x24 } , // E
  { 70, 1, 0x2B } , // F
  { 71, 1, 0x34 } , // G
  { 72, 1, 0x33 } , // H
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
  { 127, 2, 0x71 } , // Delete
  { 129, 0, 0x05 } , // F1
  { 130, 0, 0x06 } , // F2
  { 131, 0, 0x04 } , // F3
  { 132, 0, 0x0C } , // F4
  { 133, 0, 0x03 } , // F5
  { 134, 0, 0x0B } , // F6
  { 135, 0, 0x83 } , // F7
  { 136, 0, 0x0A } , // F8
  { 137, 0, 0x01 } , // F9
  { 138, 0, 0x09 } , // F10
  { 139, 2, 0x70 } , // Insert
  { 152, 2, 0x6C } , // Home
  { 153, 2, 0x7D } , // PgUp
  { 161, 0, 0x13 } , // Kana
  { 164, 2, 0x7A } , // PgDn
  { 165, 2, 0x69 } , // End
  { 180, 2, 0x6B } , // ←
  { 181, 2, 0x75 } , // ↑
  { 182, 2, 0x72 } , // ↓
  { 183, 2, 0x74 } , // →
};

uint8_t enabled = 0;              // PS/2 Host zum Senden bereit

// Durchsucht die Scan-Code-Konvertierungstabelle
int16_t findScanMap(uint8_t code) {
  int16_t no = -1;
  for (int16_t i = 0; i < 121; i++) {
    if (ScanMap[i][0] == code) {
      no = i;
      break;
    }
  }
  return no;
}

// PS/2 Sende eine Bestätigung an den Host
void ack() {
  while (keyboard.write(0xFA));
}

// PS/2 Vom Host gesendete Befehle verarbeiten
int keyboardcommand(int command) {
  unsigned char val;
  uint32_t tm;
  switch (command) {
    case 0xFF:
      ack();// Reset: Befehl zum Zurücksetzen der Tastatur. Gibt ACK zurück, wenn es korrekt empfangen wurde.
      while (keyboard.write(0xAA) != 0);
      break;
    case 0xFE: // Anfrage erneut senden
      ack();
      break;
    case 0xF6: // Kehre zum Startzustand zurück
      //enter stream mode
      ack();
      break;
    case 0xF5: //Kehre zum Startzustand zurück und stoppe den Keyscan
      //FM
      enabled = 0;
      ack();
      break;
    case 0xF4: //Keyscan starten
      //FM
      enabled = 1;
      ack();
      break;
    case 0xF3: //set typematic rate/delay :
      ack();
      if (!keyboard.read(&val)) ack(); //do nothing with the rate
      break;
    case 0xF2: //get device id :
      ack();
      keyboard.write(0xAB);
      keyboard.write(0x83);
      break;
    case 0xF0: //set scan code set
      ack();
      if (!keyboard.read(&val)) ack(); //do nothing with the rate
      break;
    case 0xEE: //echo :Wenn eine Tastatur angeschlossen ist, reagiert die Tastatur auf den Computer.（ECHO Response）Gib es zurück.
      //ack();
      keyboard.write(0xEE);
      break;
    case 0xED: //set/reset LEDs :Anfrage zum Ein-/Ausschalten der Tastatur-LED. Geben Sie die LED mit dem folgenden Optionsbyte an.
      ack();
      if (!keyboard.read(&val)) ack();; //do nothing with the rate
      ack();
      return 1;
      break;
  }
  return 1;
}

// Scancode senden
// break
// no : Datensatznummer der Scancode-Tabelle
void sendScanCode(int16_t no, int rpt_flag) {
  //****************** Repeat funktion- Test *****************************

  if (rpt_flag == 1) {
    if (ScanMap[no][1] & 1) {
      // Wenn die Umschalttaste zusammen verwendet wird, senden Sie zuerst den Scancode der rechten Umschalttaste.
      keyboard.write(0x59);
    }

    keyboard.write(ScanMap[no][2]);
    delay(10);
    return;
  }

  if (rpt_flag == 2) {
    keyboard.write(0xf0);
    keyboard.write(ScanMap[no][2]);
    if (ScanMap[no][1] & 1) {
      // Wenn die Umschalttaste zusammen verwendet wird, senden Sie zuletzt den Scancode der rechten Umschalttaste.
      keyboard.write(0xf0);
      keyboard.write(0x59);
    }
    delay(10);
    return;
  }
  //****************** Repeat funktion- Test *****************************


  // Code senden
  if (ScanMap[no][1] & 1) {
    // Wenn die Umschalttaste zusammen verwendet wird, senden Sie zuerst den Scancode der rechten Umschalttaste.
    keyboard.write(0x59);
  }

  if (ScanMap[no][1] & 2) {
    // 2-Byte-Scancode
    keyboard.write(0xe0);
  }

  if (ctrl == 1) {
    if (no > 69 && no < 96)
    {
      keyboard.write(0x14);
    }
    else ctrl = 0;                            //ctrl-Marker löschen, wenn nicht a-z gedrückt
  }

  keyboard.keyboard_mkbrk(ScanMap[no][2]);

  // Break Code senden
  if (ScanMap[no][1] & 2) {
    // 2-Byte-Scancode
    keyboard.write(0xe0);

  }
  keyboard.write(0xf0);
  keyboard.write(ScanMap[no][2]);
  //delay(10);

  if (ScanMap[no][1] & 1) {
    // Wenn die Umschalttaste zusammen verwendet wird, senden Sie zuletzt den Scancode der rechten Umschalttaste.
    keyboard.write(0xf0);
    keyboard.write(0x59);
  }

  if (ctrl == 1) {
    if (no > 69 && no < 96)
    {
      keyboard.write(0xf0);
      keyboard.write(0x14);              //FN - Key als Cntrl - Key
    }
    ctrl = 0;                            //ctrl-Marker löschen
  }

}


void flashOn() {
  pixels.setPixelColor(0, pixels.Color(3, 3, 3)); pixels.show();
}

void flashOff() {
  pixels.setPixelColor(0, pixels.Color(0, 0, 0)); pixels.show();
}


void setup() {
  //Serial.begin(115200);
  pinMode(A3, OUTPUT);
  pinMode(A2, OUTPUT);
  pinMode(A1, OUTPUT);
  pinMode(A0, OUTPUT);
  digitalWrite(A0, HIGH);
  digitalWrite(A1, LOW);
  digitalWrite(A2, LOW);
  digitalWrite(A3, LOW);
  DDRB = 0x00;
  PORTB = 0xff;
  DDRD = 0x00;
  PORTD = 0xff;

  pixels.begin();
  keyboard.keyboard_init();

}

unsigned char GetInput() {
  unsigned char k = 0;
  digitalWrite(A3, LOW);
  digitalWrite(A2, HIGH);
  digitalWrite(A1, HIGH);
  digitalWrite(A0, HIGH);
  if (PIND != 0xff) {
    switch (PIND)   {
      case 254: k = 1; break; //ESC
      case 253: k = 2; break; // 1
      case 251: k = 3; break; //2
      case 247: k = 4; break; //3
      case 239: k = 5; break; //4
      case 223: k = 6; break; //5
      case 191: k = 7; break; //6
      case 127: k =  8; break; //7
    }
  }
  else if (PIND != 223) {
    switch (PINB)   {
      case 222: k = 9; break; //8
      case 221: k = 10; break; //9
      case 219: k = 11; break; //0
      case 215: k = 12; break; //Del
    }
  }
  if (k) {
    hadPressed = 1;
    return k;
  }


  digitalWrite(A3, HIGH);
  digitalWrite(A2,  LOW);
  digitalWrite(A1, HIGH);
  digitalWrite(A0, HIGH);
  if (PIND != 0xff) {
    switch (PIND)   {
      case 254: k = 13; break; //Tab
      case 253: k = 14; break; //Q
      case 251: k = 15; break; //W
      case 247: k = 16; break; //E
      case 239: k = 17; break; //R
      case 223: k = 18; break; //T
      case 191: k = 19; break; //Y
      case 127: k = 20; break; //U
    }
  }
  else if (PIND != 223) {

    switch (PINB)   {
      case 222: k = 21; break; //I
      case 221: k = 22; break; //O
      case 219: k = 23; break; //P
      case 215: k = 24; break; //no key
    }

  }
  if (k) {
    hadPressed = 1;
    return k;
  }


  digitalWrite(A3, HIGH);
  digitalWrite(A2, HIGH);
  digitalWrite(A1, LOW);
  digitalWrite(A0, HIGH);
  if (PIND != 0xff) {
    switch (PIND)   {
      case 254: k = 25; break; //left
      case 253: k = 26; break; //up
      case 251: k = 27; break; //A
      case 247: k = 28; break; //S
      case 239: k = 29; break; //D
      case 223: k = 30; break; //F
      case 191: k = 31; break; //G
      case 127: k =  32; break; //H
    }
  }

  else if (PIND != 223) {
    switch (PINB)   {
      case 222: k = 33; break; //J
      case 221: k = 34; break; //K
      case 219: k = 35; break; //L
      case 215: k = 36; break; //Enter
    }
  }
  if (k) {
    hadPressed = 1;
    return k;
  }


  digitalWrite(A3, HIGH);
  digitalWrite(A2, HIGH);
  digitalWrite(A1, HIGH);
  digitalWrite(A0, LOW);


  if (PIND != 0xff) {

    switch (PIND)   {
      case 254: k = 37; break; //down
      case 253: k = 38; break; //right
      case 251: k = 39; break; //Z
      case 247: k = 40; break; //X
      case 239: k = 41; break; //C
      case 223: k = 42; break; //V
      case 191: k = 43; break; //B
      case 127: k = 44; break; //N
    }
  }
  else if (PIND != 223) {
    switch (PINB)   {
      case 222: k = 45; break; //M
      case 221: k = 46; break; //,
      case 219: k = 47; break; //.
      case 215: k = 48; break; //Space
    }
  }
  /*
    else {
      hadPressed = 0;
      hadRelease = 1;
      return 255;
    }
  */
  if (k) {
    hadPressed = 1;
    return k;
  }

  hadPressed = 0;
  return 255;

}


void loop() {
  unsigned char cmd;  // Vom Host gesendete Daten
  bool fl = false;
  if (keyboard.available() || startup == 0) {
    while (keyboard.read(&cmd)) ;
    startup = keyboardcommand(cmd);//a=keyboard.keyboard_reply(cmd,0);
    if (startup) {
      pixels.setPixelColor(0, pixels.Color(30, 0, 30));  //zeigt Initialisierung mit lila LED an
      pixels.show();
      delay(500);
    }
  }

  if (shiftPressed)   {

    _sym = 0; _fn = 0; idle = 0;
    while (shiftPressed)delay(1);
    if (_shift == 0)     {
      delay(300);
      if (shiftPressed)       {
        while (shiftPressed)delay(1);
        _shift = 2;
        Mode = 2;
      } else  {
        _shift = 1;
        Mode = 1;
      }
    } else {
      delay(300);
      if (shiftPressed)       {
        while (shiftPressed)delay(1);
        if (_shift == 2)         {
          Mode = 0;
          _shift = 0;
        } else  {
          Mode = 2;
          _shift = 2;
        }
      } else  {
        Mode = 0;
        _shift = 0;
      }
    }
  }

  if (symPressed)   {
    _shift = 0; _fn = 0; idle = 0;
    while (symPressed)delay(1);
    if (_sym == 0)     {
      delay(300);
      if (symPressed)       {
        while (symPressed)delay(1);
        _sym = 2;
        Mode = 4;
      } else  {
        _sym = 1;
        Mode = 3;
      }
    } else {
      delay(300);
      if (symPressed)  {
        while (symPressed)delay(1);
        if (_sym == 2)  {
          Mode = 0;
          _sym = 0;
        } else  {
          Mode = 4;
          _sym = 2;
        }
      } else {
        Mode = 0;
        _sym = 0;
      }
    }
  }

  if (fnPressed) {
    _sym = 0; _shift = 0; idle = 0;
    while (fnPressed)delay(1);
    if (_fn == 0) {
      ctrl = 1;                             //Ctrl-Funktion
      delay(300);
      if (fnPressed) {
        while (fnPressed)delay(1);
        _fn = 2;
        Mode = 6;
      } else  {
        _fn = 1;
        Mode = 5;
      }
    } else
    {
      delay(300);
      if (fnPressed) {
        while (fnPressed)delay(1);
        if (_fn == 2) {
          Mode = 0;
          _fn = 0;
          ctrl = 0;
        } else {
          Mode = 6;
          _fn = 2;
        }
      } else {
        Mode = 0;
        _fn = 0;
        ctrl = 0;
      }
    }
  }

  switch (Mode)  {
    case 0://normal
      pixels.setPixelColor(0, pixels.Color(0, 0, 0)); break;
    case 1://shift
      if ((idle / 6) % 2 == 1)
        pixels.setPixelColor(0, pixels.Color(0, 0, 0));
      else
        pixels.setPixelColor(0, pixels.Color(5, 0, 0)); break;
    case 2://long_shift
      pixels.setPixelColor(0, pixels.Color(5, 0, 0)); break;
    case 3://sym
      if ((idle / 6) % 2 == 1)
        pixels.setPixelColor(0, pixels.Color(0, 0, 0));
      else
        pixels.setPixelColor(0, pixels.Color(0, 5, 0)); break;
    case 4://long_sym
      pixels.setPixelColor(0, pixels.Color(0, 5, 0)); break;
    case 5://fn
      if ((idle / 6) % 2 == 1)
        pixels.setPixelColor(0, pixels.Color(0, 0, 0));
      else
        pixels.setPixelColor(0, pixels.Color(0, 0, 5)); break;
    case 6://long_fn
      pixels.setPixelColor(0, pixels.Color(0, 0, 5)); break;
  }

  pixels.show(); // This sends the updated pixel color to the hardware.

  if (hadPressed == 0)   {
    KEY = GetInput();
  }

  // PS/2 Scancode senden
  if (hadPressed == 1) {
    uint8_t c = KeyMap[KEY - 1][Mode];
    int16_t no = findScanMap(c);
    if (no >= 0) {
      flashOn();
      if (old_no != no) {
        sendScanCode(no, 0);  //erstes mal Taste - 200ms Verzögerung
        first_no = no;
        repeatkey = 0;
        delay(230);
      }
      else {
        sendScanCode(no, 1);  //zweites bis n.tes mal Tastenrepeat 33ms
        repeatkey = 1;
        delay(70);
      }
      old_no = no;
    }

    flashOff();
    if ((Mode == 1) || (Mode == 3) || (Mode == 5)) {
      Mode = 0;
      _shift = 0;
      _sym = 0;
      _fn = 0;
    }
    hadPressed = 0;
  }


  if (hadPressed == 0) idle++;
  if (idle > 30) {                             //verhindert, das wenn man die gleiche Taste nach etwa 300ms nochmal drückt der Repeatmodus eingeschaltet ist, das verhindert doppelte Zeichen
    if (old_no == first_no && repeatkey == 1 ) sendScanCode(first_no, 2);
    old_no = -1;
    first_no = -1;
    repeatkey = 0;


    fl = !fl;
    if (fl) pixels.setPixelColor(0, pixels.Color(5, 0, 5));  //Lebenspuls - zeigt an, das die Tastatur funktionsfähig ist
    pixels.show();
    idle = 0;
  }

  delay(8);

}

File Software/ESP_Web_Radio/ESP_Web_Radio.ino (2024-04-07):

/*
  // ******************** ESP-Webradio Version 1.0 03/2024 *************************
  // als Betandteil des Basic32+ Projektes als ladbares Programm mit der Grafik-
  // Bibliothek FabGl - Dank an Fabrizio Di Vittorio
  // Bedienung: <- und -> (Pfeil-)Tasten schaltet durch die Sender (20)
  // Taste ESC kehrt zum Basic32+ zurück
  // Programm kommt ohne externe I2S Hardware aus, Audio-Ausgabe über Pin 25
  // sonstige Hardwarekonfiguration siehe Basic32+
  // created by R.Zielinski - Berlin
  // Nutzung auf eigene Gefahr!!! :-)
  // *******************************************************************************
*/
#include <Arduino.h>

#include <Preferences.h>
#include <WiFi.h>


#include "AudioFileSourceICYStream.h"
#include "AudioFileSourceBuffer.h"
#include "AudioGeneratorMP3.h"
#include "AudioOutputI2S.h"
#include "cfg.h"   //********************************************* Konfigurations-Datei *************************************************************

#include "fabgl.h" //********************************************* Bibliotheken zur VGA-Signalerzeugung *********************************************

fabgl::Terminal         Terminal;
fabgl::LineEditor       LineEditor(&Terminal);

//---------------------------------------- die verschiedenen Grafiktreiber --------------------------------------------------------------------------
#ifdef AVOUT
fabgl::CVBS16Controller VGAController;    //AV-Variante
#define VIDEOOUT_GPIO GPIO_NUM_26         //Ausgabe auf GPIO25 oder 26 möglich ACHTUNG!:Soundausgabe erfolgt auf GPIO25
static const char * MODES_STD[]   = { "I-PAL-B", "P-PAL-B", "I-NTSC-M", "P-NTSC-M", "I-PAL-B-WIDE", "P-PAL-B-WIDE", "I-NTSC-M-WIDE", "P-NTSC-M-WIDE", "P-NTSC-M-EXT",};

#elif defined VGA64
fabgl::VGA16Controller    VGAController;      //VGA-Variante -> max.16 Farben, sonst reicht der Speicher nicht zum streamen

#else
fabgl::ILI9341Controller VGAController;     //TFT-Display ILI9341
#endif


//------------------------------------------ Tastatur,GFX-Treiber- und Terminaltreiber -------------------------------------------------------------
fabgl::PS2Controller    PS2Controller;
fabgl::Keyboard Keyboard;
fabgl::Canvas           GFX(&VGAController);
TerminalController      tc(&Terminal);
// where to store WiFi info, etc...
Preferences preferences;

//------------------------------ I2C Library ------------------------------------------------------------------------------------------------------
#include <Wire.h>           // for I2C 
#include "RTClib.h"         //to show time
TwoWire myI2C = TwoWire(0); //eigenen I2C-Bus erstellen
RTC_DS3231 rtc;
// dies ist die Standard-Konfiguration
byte SDA_RTC = 3;
byte SCL_RTC = 1;
short int EEprom_ADDR = 0x57; //-> Adresse 0x57 ist der EEPROM auf dem RTC3231 Cord
byte station_eep = 0;         //     // an der Adresse 0x7fff wird die Station gespeichert

unsigned int Datum[4];                   //Datums-Array
unsigned int Zeit[4];                    //Zeit-Array
unsigned int tmp_zeit;                   //vergleichswert für Zeitaktualisierung im Display
// ---------------------------------- SD-Karten-Zugriff--------------------------------------------------------------------------------------------
#include <SD.h>
#include <SPI.h>
const char*  Radio_Pics[] PROGMEM = {"Radio1.bmp", "Radio2.bmp"};
char tempstring[40];                //String Zwischenspeicher
int filenums = 2;
//-------------------------------------- Verwendung der SD-Karte ----------------------------------------------------------------------------------
//SPI CLASS FOR REDEFINED SPI PINS !
SPIClass spiSD(HSPI);
#define kSD_Fail  0      //Fehler-Marker
#define kSD_OK    1      //OK-Marker
File fp;
//------------------------------------- OTA-Update-Lib --------------------------------------------------------------------------------------------
#include <Update.h>

uint32_t bmp_width, bmp_height;
const char* filetype[] = {".bin", ".bmp"};
static char sd_pfad[2];            //SD-Card Datei-Pfad

int Key_l = 0;
int Key_r = 0;
int Key_u = 0;
int Key_d = 0;

//int title_length = 0;
uint8_t curGain = 200;    //current loudness

bool Key_esc = false;
bool Key_save = false;
bool Key_wifi = false;



// URL of internet radio station
const char *URL[] PROGMEM = {
  "http://www.golden-apple.com:680/;",
  "http://46.163.75.84:8000/",
  "http://countrymusic24.powerstream.de:9000/",
  "http://stream2.jenny.fm:9000/",
  "http://de1.streamhosting.ch:8050/",
  "http://www.memoryradio.de:4000/",
  "http://radio1.nightline-radio.de:8000/",
  "http://streaming.fueralle.org:8000/corax.mp3",
  "http://streaming.fueralle.org:8000/Radio-F.R.E.I",
  "http://streaming.fueralle.org:8000/frs-hi.mp3",
  "http://streaming.fueralle.org:8000/frn",
  "http://streaming.fueralle.org:8000/bermudafunk_low",
  "http://streaming.fueralle.org:8000/radiot.mp3",
  "http://streaming.fueralle.org:8000/rfk",
  "http://streaming.fueralle.org:8000/slubfurt_128.mp3",
  "https://onair.dancewave.online:8082/dance.mp3?_ic2=1709836317186",
  "http://topradio-de-hz-fal-stream02-cluster01.radiohost.de/brf_mp3-128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",
  "http://orf-live.ors-shoutcast.at/oe3-q1a",
  "http://mp3.ffh.de/radioffh/hqlivestream.mp3",
  "http://cafe80s.eu:8100/"
};


const char* title[] PROGMEM = {"Golden Apple", "Hitradio Potsdam", "Countrymusic24", "JennyFM", "Lounge Grooves", "MemoryRadio",
                               "Nightline Radio", "Radio Corax", "Radio-F.R.E.I", "Radio Stuttgart", "Radio Neumuenster", "Bermudafunk",
                               "Radio T Chemnitz", "Rundfunkkombinat", "Buerger-Radio", "Dance Wave!", "Berliner Rundfunk", "ORF Hitradio",
                               "HitRadio FFH", "Cafe 80s FM"
                              };
int    x_position[] PROGMEM = {140 , 122 , 132, 167 , 132, 147, 127, 147 , 137 , 127 , 117 , 147, 122, 122, 127, 147, 117, 142, 142, 147}; //194-(10xZeichenzahl)/2+105 ->Anzeige mittig
int stations = 20;
int act_station = 0;

AudioGeneratorMP3 *mp3;
AudioFileSourceICYStream *file;
AudioFileSourceBuffer *buff;
AudioOutputI2S *out;


const char* Edit_line = nullptr;        //Editor-Zeile

char ssid[32] = "";
char pwd[32]  = "";



void fcolor(int fc) {
  GFX.setPenColor((bitRead(fc, 5) * 2 + bitRead(fc, 4)) * 64, (bitRead(fc, 3) * 2 + bitRead(fc, 2)) * 64, (bitRead(fc, 1) * 2 + bitRead(fc, 0)) * 64);
}

void bcolor(int bc) {
  GFX.setBrushColor((bitRead(bc, 5) * 2 + bitRead(bc, 4)) * 64, (bitRead(bc, 3) * 2 + bitRead(bc, 2)) * 64, (bitRead(bc, 1) * 2 + bitRead(bc, 0)) * 64);
}


void MDCallback(void *cbData, const char *type, bool isUnicode, const char *string)
{ char title[32];
  if (strstr_P(type, PSTR("Title"))) {
    strncpy(title, string, sizeof(title));
    title[sizeof(title) - 1] = 0;
    GFX.fillRectangle(105, 130, 299, 139);
    drawing_text(2, 105, 132, title);
  };
}
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

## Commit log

2024-03-30 add volume control
    [Port-Belegung.ods]
2024-04-05 Schematic update
    [ESP32_VGA_Pocket.brd, ESP32_VGA_Pocket.sch, tastatur.brd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]
